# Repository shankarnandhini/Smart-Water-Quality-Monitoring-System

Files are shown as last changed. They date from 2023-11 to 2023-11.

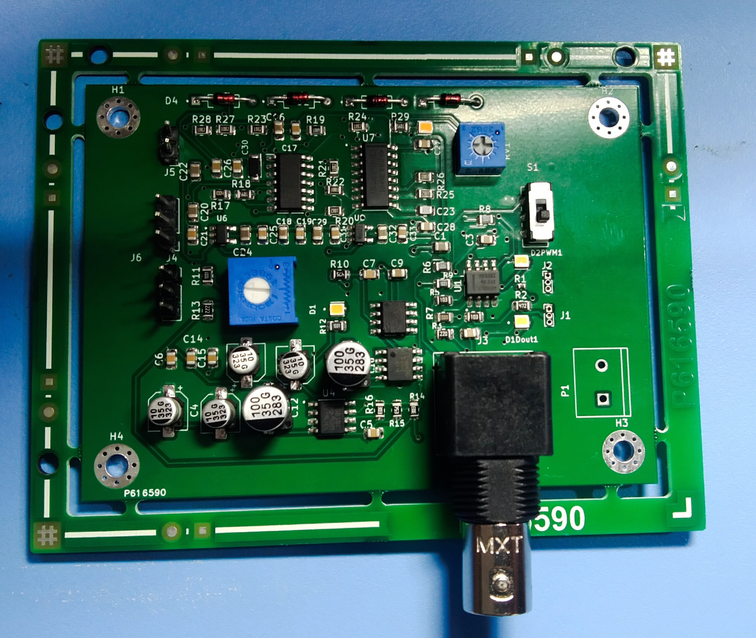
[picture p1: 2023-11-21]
Product image/IMG_20231109_144141.jpg

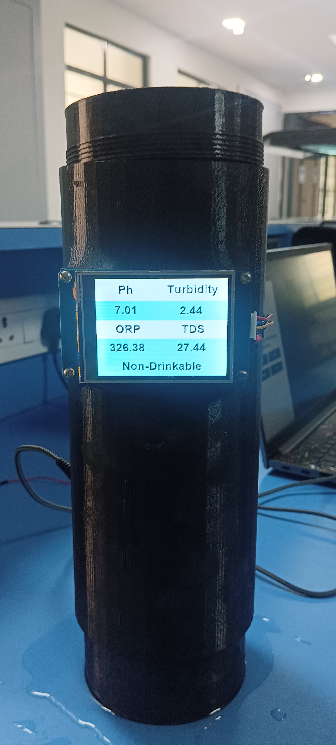
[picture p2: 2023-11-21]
Product image/IMG-20231110-WA0006.jpg

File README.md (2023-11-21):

# Smart-Water-Quality-Monitoring-System
# 🌐 Smart Water Quality Monitoring System Repository

Welcome to the repository for our Smart Water Quality Monitoring System! 🚰

## Project Overview

This repository hosts the code and documentation for an innovative smart water quality monitoring system. Our goal is to provide real-time insights into the quality of drinking water through a seamlessly integrated system.

## Key Components

- **Double-layer PCB Design:** Schematics and layouts meticulously crafted for enhanced performance.
  
- **3D-Printed Sensor Housings:** Custom-designed sensor housings using advanced 3D printing techniques.
  
- **Industrial Sensors:** Integration of industrial-grade pH, ORP, TDS, and turbidity sensors for accurate readings.

- **Raspberry Pi 4:** The core of our system, handling data processing and communication tasks efficiently.

- **Nextion HMI Touch Display:** An interactive touch display for real-time data visualization.

- **Mobile Application:** Developed using React Native, Node.js Express, and a robust database for accessible monitoring.

## Contributions

- **PCB Design:** Developed intricate double-layer PCB schematics and layouts.
  
- **3D Design and Printing:** Created and printed custom sensor housings for optimal functionality.
  
- **Hardware Integration:** Seamlessly integrated various hardware components and peripherals.
  
- **Raspberry Pi Programming:** Wrote the necessary code for Raspberry Pi, ensuring smooth data processing and communication.
  
- **Mobile Application Development:** Utilized React Native, Node.js Express, and database technologies for a user-friendly mobile application.

## Skills and Technologies Showcased

- **PCB Design:** Proficiency in crafting intricate PCB schematics and layouts.
  
- **3D Design and Printing:** Skillful creation and printing of custom 3D sensor housings.
  
- **Hardware Integration:** Expertise in integrating diverse hardware components seamlessly.
  
- **Raspberry Pi Programming:** Coding proficiency for efficient data processing on Raspberry Pi.
  
- **React Native:** Development of a mobile application for versatile accessibility.
  
- **Node.js Express:** Utilized for the backend of the mobile application.
  
- **Database Technologies:** Implemented a robust database for storing and managing data.

## License

This project is licensed under the MIT License
## Collaboration

This project is open to all collaborators! Feel free to contribute by forking the repository and creating pull requests.

## Documentation

Check the folders for comprehensive documentation related to the Smart Water Quality Monitoring System.

Feel free to explore the codebase and documentation to understand the inner workings of our Smart Water Quality Monitoring System! 💻🚀

#WaterQuality #SmartMonitoring #OpenSource #TechInnovation

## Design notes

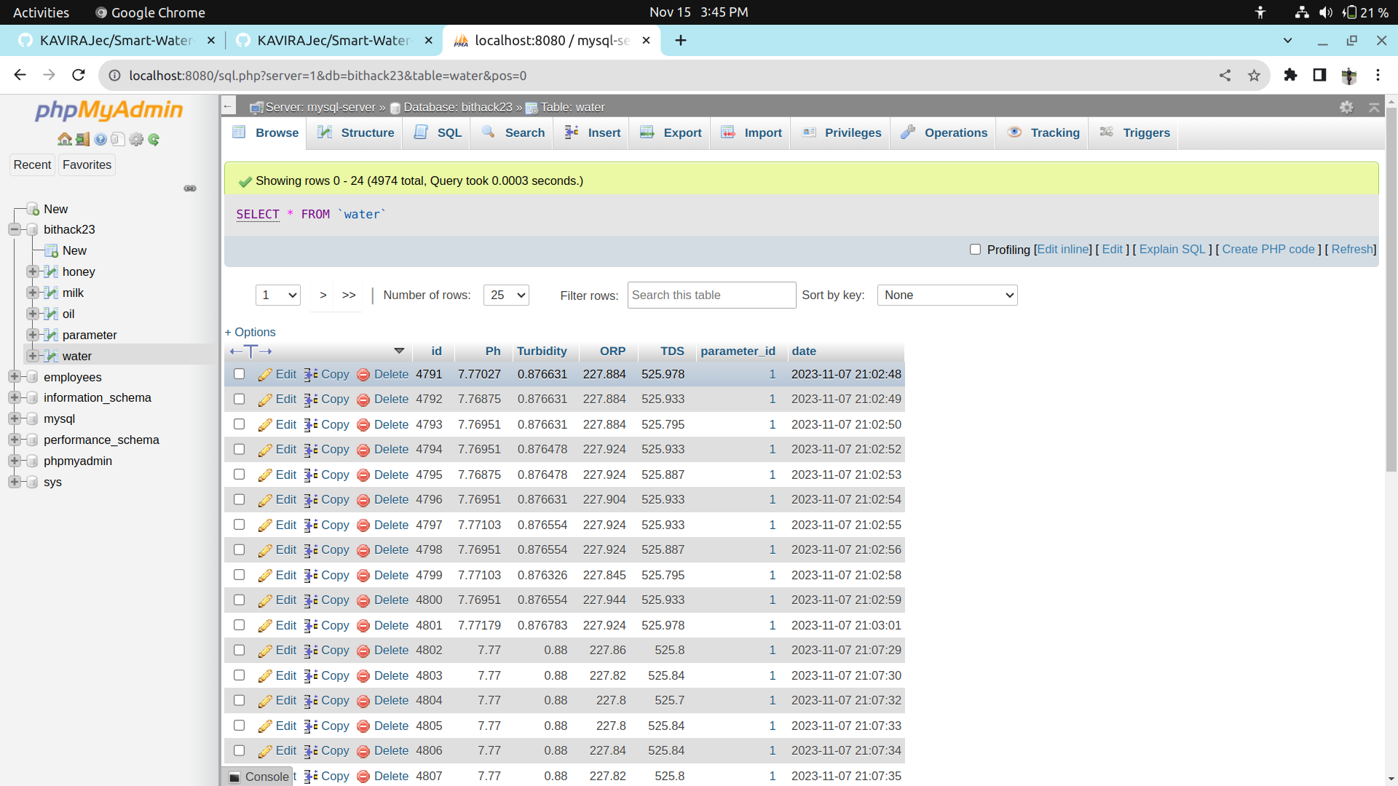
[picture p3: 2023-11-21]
Mobile Application/Screenshot from 2023-11-15 15-45-17.png

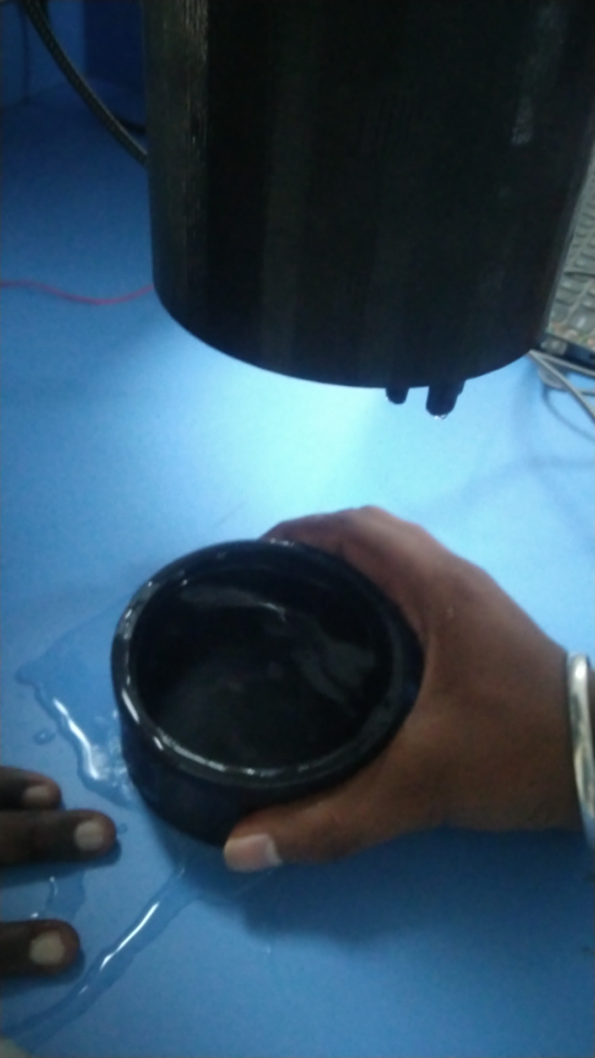
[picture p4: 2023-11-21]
Product image/Screenshot_20231115_143211.png

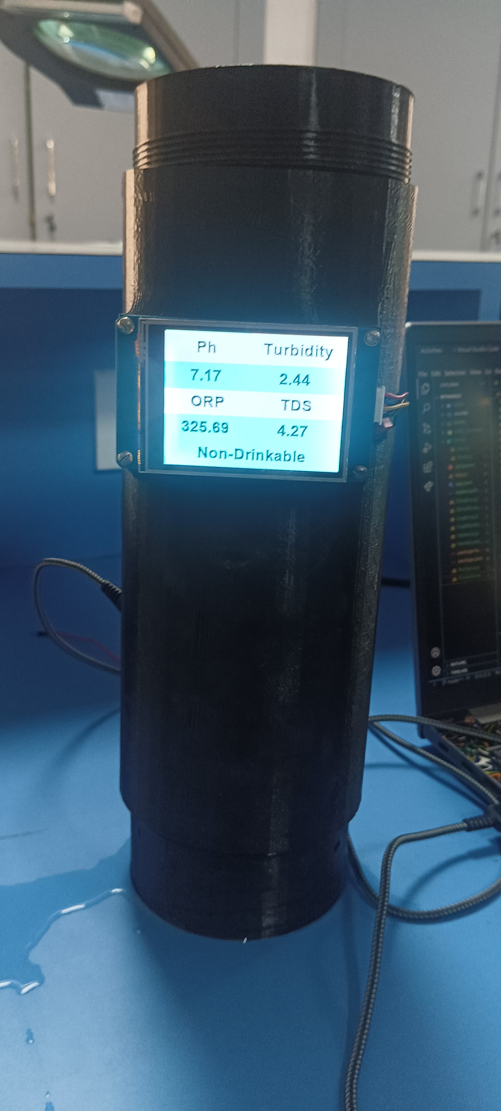
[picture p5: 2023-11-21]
Product image/IMG-20231110-WA0005.jpg

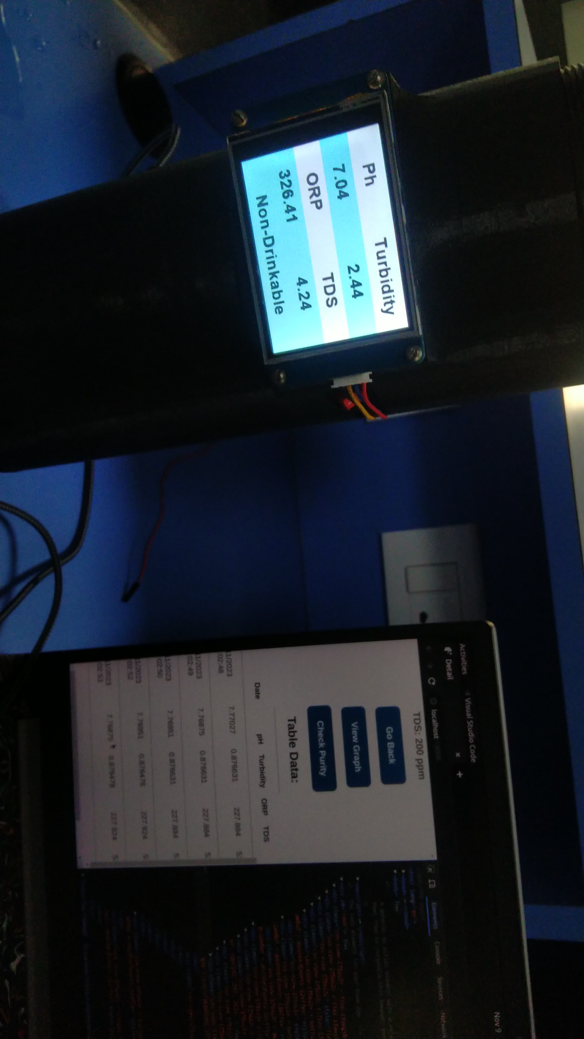
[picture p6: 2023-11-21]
Product image/Screenshot_20231115_143034.png

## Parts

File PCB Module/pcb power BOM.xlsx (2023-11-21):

BILL OF MATERIAL
Item | Quantity | Reference | Value | PART TYPE | PCB Footprint | Manufacturer Part Number | Manfacturer Name | Description
1 | 1 | C1 | 10uF | CAP | C_0805_2012Metric | CL21A106KOCLRNC | Samsung Electro-Mechanics | 10 µF ±10% 16V Ceramic Capacitor X5R 0805 (2012 Metric)(3.4mm*1.96mm)
2 | 1 | C4 | 10uF | Polarized CAP | CP_Elec_5x3 | EDK106M035A9BAA | KEMET | 10 µF 35 V Aluminum Electrolytic Capacitors Radial, Can - SMD 2000 Hrs @ 85°C(7.9mm*5.8mm)
3 | 1 | C8 | 10uF | Polarized CAP | CP_Elec_5x3 | EDK106M035A9BAA | KEMET | 10 µF 35 V Aluminum Electrolytic Capacitors Radial, Can - SMD 2000 Hrs @ 85°C(7.9mm*5.8mm)
4 | 1 | C9 | 1uF | CAP | C_0805_2012Metric | CL21B105KAFNNNE | Samsung Electro-Mechanics | 1 µF ±10% 25V Ceramic Capacitor X7R 0805 (2012 Metric)(3.6mm*1.96mm)
5 | 1 | C10 | 100uF | Polaroid CAP | CP_Elec_5x3 | EDK107M035A9HAA | KEMET | 100 µF 35 V Aluminum Electrolytic Capacitors Radial, Can - SMD 2000 Hrs @ 85°C(7.9mm*5.8mm)
6 | 1 | C11 | 10uF | Polarized CAP | CP_Elec_5x3 | EDK106M035A9BAA | KEMET | 10 µF 35 V Aluminum Electrolytic Capacitors Radial, Can - SMD 2000 Hrs @ 85°C(7.9mm*5.8mm)
7 | 1 | C12 | 100uF | Polarized CAP | CP_Elec_5x3 | EDK107M035A9HAA | KEMET | 100 µF 35 V Aluminum Electrolytic Capacitors Radial, Can - SMD 2000 Hrs @ 85°C(7.9mm*5.8mm)
8 | 1 | C13 | 10uF | Polarized CAP | CP_Elec_5x3 | EDK106M035A9BAA | KEMET | 10 µF 35 V Aluminum Electrolytic Capacitors Radial, Can - SMD 2000 Hrs @ 85°C(7.9mm*5.8mm)
9 | 1 | C16 | 4.7uF | CAP | C_0805_2012Metric | CL21A475KAQNNNE | Samsung Electro-Mechanics | 4.7 µF ±10% 25V Ceramic Capacitor X5R 0805 (2012 Metric)(3.4mm*1.96mm)
10 | 1 | C18 | 4.7uF | CAP | C_0805_2012Metric | CL21A475KAQNNNE | Samsung Electro-Mechanics | 4.7 µF ±10% 25V Ceramic Capacitor X5R 0805 (2012 Metric)(3.4mm*1.96mm)
11 | 1 | C20 | 10uF | CAP | C_0805_2012Metric | CL21A106KOCLRNC | Samsung Electro-Mechanics | 10 µF ±10% 16V Ceramic Capacitor X5R 0805 (2012 Metric)(3.4mm*1.96mm)
12 | 1 | C22 | 10uF | CAP | C_0805_2012Metric | CL21A106KOCLRNC | Samsung Electro-Mechanics | 10 µF ±10% 16V Ceramic Capacitor X5R 0805 (2012 Metric)(3.4mm*1.96mm)
13 | 1 | C24 | 10uF | CAP | C_0805_2012Metric | CL21A106KOCLRNC | Samsung Electro-Mechanics | 10 µF ±10% 16V Ceramic Capacitor X5R 0805 (2012 Metric)(3.4mm*1.96mm)
14 | 1 | C26 | 1uF | CAP | C_0805_2012Metric | CL21B105KAFNNNE | Samsung Electro-Mechanics | 1 µF ±10% 25V Ceramic Capacitor X7R 0805 (2012 Metric)(3.4mm*1.96mm)
15 | 1 | C29 | 10uF | CAP | C_0805_2012Metric | CL21A106KOCLRNC | Samsung Electro-Mechanics | 10 µF ±10% 16V Ceramic Capacitor X5R 0805 (2012 Metric)(3.4mm*1.96mm)
16 | 1 | C30 | 1uF | CAP | C_0805_2012Metric | CL21B105KAFNNNE | Samsung Electro-Mechanics | 1 µF ±10% 25V Ceramic Capacitor X7R 0805 (2012 Metric)(3.4mm*1.96mm)
17 | 1 | C32 | 10uF | CAP | C_0805_2012Metric | CL21A106KOCLRNC | Samsung Electro-Mechanics | 10 µF ±10% 16V Ceramic Capacitor X5R 0805 (2012 Metric)(3.4mm*1.96mm)
18 | 1 | R1 | 500R | RES | Resistor_SMD:R_0402_2012Metric | PNM0402E5000BST1 | Vishay Dale Thin Film | 500 Ohms ±0.1% 0.05W, 1/20W Chip Resistor 0402 (1005 Metric) Anti-Sulfur, Moisture Resistant, Non-Inductive, Non-Magnetic Thin Film(3.36mm*1.9mm)
19 | 1 | R2 | 4.7K | RES | Resistor_SMD:R_0805_2012Metric | RC0805JR-074K7L | YAGEO | 4.7 kOhms ±5% 0.125W, 1/8W Chip Resistor 0805 (2012 Metric) Moisture Resistant Thick Film
20 | 1 | R3 | 22 ohm | RES | Resistor_SMD:R_0805_2012Metric | RC0805JR-0722RL | YAGEO | 22 Ohms ±5% 0.125W, 1/8W Chip Resistor 0805 (2012 Metric) Moisture Resistant Thick Film(3.36mm*1.9mm)
21 | 1 | R4 | 10K | RES | Resistor_SMD:R_0805_2012Metric | RC0805JR-0710KL | YAGEO | 10 kOhms ±5% 0.125W, 1/8W Chip Resistor 0805 (2012 Metric) Moisture Resistant Thick Film(3.36mm*1.9mm)
22 | 1 | R5 | 10K | RES | Resistor_SMD:R_0805_2012Metric | RC0805JR-0710KL | YAGEO | 10 kOhms ±5% 0.125W, 1/8W Chip Resistor 0805 (2012 Metric) Moisture Resistant Thick Film(3.36mm*1.9mm)
23 | 1 | R6 | 1K | RES | Resistor_SMD:R_0805_2012Metric | RNCP0805FTD1K00 | Stackpole Electronics Inc | 1 kOhms ±1% 0.25W, 1/4W Chip Resistor 0805 (2012 Metric) Anti-Sulfur Thin Film(3.36mm*1.9mm)
24 | 1 | R7 | 100R | RES | Resistor_SMD:R_0805_2012Metric | RN73C2A100RBTDF | TE Connectivity Passive Product | 100 Ohms ±0.1% 0.1W, 1/10W Chip Resistor 0805 (2012 Metric) Thin Film(3.36mm*1.9mm)
25 | 1 | R8 | 1K | RES | Resistor_SMD:R_0805_2012Metric | RNCP0805FTD1K00 | Stackpole Electronics Inc | 1 kOhms ±1% 0.25W, 1/4W Chip Resistor 0805 (2012 Metric) Anti-Sulfur Thin Film(3.36mm*1.9mm)
26 | 1 | R9 | 1K | RES | Resistor_SMD:R_0805_2012Metric | RNCP0805FTD1K00 | Stackpole Electronics Inc | 1 kOhms ±1% 0.25W, 1/4W Chip Resistor 0805 (2012 Metric) Anti-Sulfur Thin Film(3.36mm*1.9mm)
27 | 1 | R10 | 4.7M | RES | Resistor_SMD:R_0805_2012Metric | RC0805JR-074M7L | YAGEO | 4.7 MOhms ±5% 0.125W, 1/8W Chip Resistor 0805 (2012 Metric) Moisture Resistant Thick Film(3.36mm*1.9mm)
28 | 1 | R11 | 1K | RES | Resistor_SMD:R_0805_2012Metric | RNCP0805FTD1K00 | Stackpole Electronics Inc | 1 kOhms ±1% 0.25W, 1/4W Chip Resistor 0805 (2012 Metric) Anti-Sulfur Thin Film(3.36mm*1.9mm)
29 | 1 | R12 | 1K | RES | Resistor_SMD:R_0805_2012Metric | RNCP0805FTD1K00 | Stackpole Electronics Inc | 1 kOhms ±1% 0.25W, 1/4W Chip Resistor 0805 (2012 Metric) Anti-Sulfur Thin Film(3.36mm*1.9mm)
30 | 1 | R13 | 2.2K | RES | Resistor_SMD:R_0805_2012Metric | RC0805JR-072K2L | YAGEO | 2.2 kOhms ±5% 0.125W, 1/8W Chip Resistor 0805 (2012 Metric) Moisture Resistant Thick Film(3.36mm*1.9mm)
31 | 1 | R14 | 30K | RES | Resistor_SMD:R_0805_2012Metric | RC0805JR-0730KL | YAGEO | 30 kOhms ±5% 0.125W, 1/8W Chip Resistor 0805 (2012 Metric) Moisture Resistant Thick Film(3.36mm*1.9mm)
32 | 1 | R15 | 75K | RES | Resistor_SMD:R_0805_2012Metric | RC0805JR-0775KL | YAGEO | 75 kOhms ±5% 0.125W, 1/8W Chip Resistor 0805 (2012 Metric) Moisture Resistant Thick Film(3.36mm*1.9mm)
33 | 1 | R16 | 30K | RES | Resistor_SMD:R_0805_2012Metric | RC0805JR-0730KL | YAGEO | 30 kOhms ±5% 0.125W, 1/8W Chip Resistor 0805 (2012 Metric) Moisture Resistant Thick Film(3.36mm*1.9mm)
34 | 1 | R17 | 1M-1% | RES-1%Tolerence | Resistor_SMD:R_0805_2012Metric | CRG0805F1M0 | TE Connectivity Passive Product | 1 MOhms ±1% 0.125W, 1/8W Chip Resistor 0805 (2012 Metric) Thick Film(3.36mm*1.9mm)
35 | 1 | R18 | 5.6K-1% | RES-1%Tolerence | Resistor_SMD:R_0805_2012Metric | RMCF0805FT5K60 | Stackpole Electronics Inc | 5.6 kOhms ±1% 0.125W, 1/8W Chip Resistor 0805 (2012 Metric) Automotive AEC-Q200 Thick Film(3.36mm*1.9mm)
36 | 1 | R19 | 6.8K-1% | RES-1%Tolerence | Resistor_SMD:R_0805_2012Metric | RMCF0805FT6K80 | Stackpole Electronics Inc | 6.8 kOhms ±1% 0.125W, 1/8W Chip Resistor 0805 (2012 Metric) Automotive AEC-Q200 Thick Film
37 | 1 | R20 | 10K-1% | RES-1%Tolerence | Resistor_SMD:R_0805_2012Metric | RMCF0805FT10K0 | Stackpole Electronics Inc | 10 kOhms ±1% 0.125W, 1/8W Chip Resistor 0805 (2012 Metric) Automotive AEC-Q200 Thick Film
38 | 1 | R21 | 10K-1% | RES-1%Tolerence | Resistor_SMD:R_0805_2012Metric | RMCF0805FT10K0 | Stackpole Electronics Inc | 10 kOhms ±1% 0.125W, 1/8W Chip Resistor 0805 (2012 Metric) Automotive AEC-Q200 Thick Film
39 | 1 | R22 | 100K-1% | RES-1%Tolerence | Resistor_SMD:R_0805_2012Metric | RMCF0805FT100K | Stackpole Electronics Inc | 100 kOhms ±1% 0.125W, 1/8W Chip Resistor 0805 (2012 Metric) Automotive AEC-Q200 Thick Film
40 | 1 | R23 | 10K-1% | RES-1%Tolerence | Resistor_SMD:R_0805_2012Metric | RMCF0805FT10K0 | Stackpole Electronics Inc | 10 kOhms ±1% 0.125W, 1/8W Chip Resistor 0805 (2012 Metric) Automotive AEC-Q200 Thick Film
41 | 1 | R24 | 10K-1% | RES-1%Tolerence | Resistor_SMD:R_0805_2012Metric | RMCF0805FT10K0 | Stackpole Electronics Inc | 10 kOhms ±1% 0.125W, 1/8W Chip Resistor 0805 (2012 Metric) Automotive AEC-Q200 Thick Film
42 | 1 | R25 | 10K-1% | RES-1%Tolerence | Resistor_SMD:R_0805_2012Metric | RMCF0805FT10K0 | Stackpole Electronics Inc | 10 kOhms ±1% 0.125W, 1/8W Chip Resistor 0805 (2012 Metric) Automotive AEC-Q200 Thick Film
43 | 1 | R26 | 100K-1% | RES-1%Tolerence | Resistor_SMD:R_0805_2012Metric | RMCF0805FT100K | Stackpole Electronics Inc | 100 kOhms ±1% 0.125W, 1/8W Chip Resistor 0805 (2012 Metric) Automotive AEC-Q200 Thick Film
44 | 1 | R27 | 10K-1% | RES-1%Tolerence | Resistor_SMD:R_0805_2012Metric | RMCF0805FT10K0 | Stackpole Electronics Inc | 10 kOhms ±1% 0.125W, 1/8W Chip Resistor 0805 (2012 Metric) Automotive AEC-Q200 Thick Film
45 | 1 | R28 | 10K-1% | RES-1%Tolerence | Resistor_SMD:R_0805_2012Metric | RMCF0805FT10K0 | Stackpole Electronics Inc | 10 kOhms ±1% 0.125W, 1/8W Chip Resistor 0805 (2012 Metric) Automotive AEC-Q200 Thick Film
46 | 1 | R29 | 5.6K-1% | RES-1%Tolerence | Resistor_SMD:R_0805_2012Metric | RMCF0805FT5K60 | Stackpole Electronics Inc | 5.6 kOhms ±1% 0.125W, 1/8W Chip Resistor 0805 (2012 Metric) Automotive AEC-Q200 Thick Film
47 | 1 | RV1 | 10K | Terminal | Potentiometer_ACP_CA9-V10_Vertical | 3362P-1-103LF | Bourns Inc. | 10 kOhms 0.5W, 1/2W PC Pins Through Hole Trimmer Potentiometer Cermet 1.0 Turn Top Adjustment(12.9mm*10.35mm)
48 | 1 | RV2 | 5K | Terminal | Potentiometer_ACP_CA9-V10_Vertical | 3386P-1-502LF | Bourns Inc. | 5 kOhms 0.5W, 1/2W PC Pins Through Hole Trimmer Potentiometer Cermet 1.0 Turn Top Adjustment(12.9mm*10.35mm)
49 | 1 | D1 | LED | White led SMD | LED_SMD:LED_0805_2012Metric | MP-2016-1100-27-90 | Luminus Devices Inc. | LED Lighting MP-2016 White, Warm 2700K 3V 60mA 110° 0806 (2016 Metric)(2.965mm*1.46mm)
50 | 1 | D1Dout1 | LED | White led SMD | LED_SMD:LED_0805_2012Metric | MP-2016-1100-27-90 | Luminus Devices Inc. | LED Lighting MP-2016 White, Warm 2700K 3V 60mA 110° 0806 (2016 Metric)(2.965mm*1.46mm)
51 | 1 | D2PWM1 | LED | White led SMD | LED_SMD:LED_0805_2012Metric | MP-2016-1100-27-90 | Luminus Devices Inc. | LED Lighting MP-2016 White, Warm 2700K 3V 60mA 110° 0806 (2016 Metric)
52 | 1 | D6 | 1N5819W | Diode | KiCad1N5819W:SODFL3618X110N | 1N5819W | SMC Diode Solutions | DIODE SCHOTTKY 40V 1A SOD123FL
53 | 1 | D7 | LED | White led SMD | LED_SMD:LED_0805_2012Metric | MP-2016-1100-27-90 | Luminus Devices Inc. | LED Lighting MP-2016 White, Warm 2700K 3V 60mA 110° 0806 (2016 Metric)
54 | 1 | J1 | Conn_01x03_pin | Male Berg Strip | Connector_PinHeader_1.00mm:PinHeader_1x03_P1.00mm_Vertical | Male Berg Strip | Male Berg Strip | Male Berg Strip
55 | 1 | J2 | Conn_01x03_pin | Male Berg Strip | Connector_PinHeader_1.00mm:PinHeader_1x03_P1.00mm_Vertical | Male Berg Strip | Male Berg Strip | Male Berg Strip
56 | 1 | J3 | Conn_Coaxial | Ph connector | Connector_Coaxial:BNC_Amphenol_B6252HB-NPP3G-50_Horizontal | 731375003 | Molex | BNC Connector Jack, Female Socket 50 Ohms Panel Mount, Through Hole, Right Angle Solder
57 | 1 | J4 | Conn_01x03_pin | Female Berg Strip | Connector_PinSocket_2.54mm:PinSocket_1x03_P2.54mm_Vertical | Female Berg Strip | Female Berg Strip | Female Berg Strip
58 | 1 | J5 | Conn_01x02_pin | Male Berg Strip | Connector_PinHeader_2.54mm:PinHeader_1x02_P2.54mm_Vertical | Male Berg Strip | Male Berg Strip | Male Berg Strip
59 | 1 | J6 | Conn_01x03_pin | Male Berg Strip | Connector_PinHeader_2.54mm:PinHeader_1x02_P2.54mm_Vertical | Male Berg Strip | Male Berg Strip | Male Berg Strip
60 | 1 | U1 | LMV358IDR | IC 8 PIN | Package_CSP:LFCSP-8_2x2mm_P0.5mm | LMV358IDR | Texas Instruments (https://www.digikey.in/en/supplier-centers/texas-instruments) | IC OPAMP GP 2 CIRCUIT 8SOIC, General Purpose Amplifier 2 Circuit Rail-to-Rail 8-SOIC
61 | 1 | U2 | CA3140AMZ | IC 8 PIN | CA3140AMZ:SOIC127P600X175-8N | CA3140AMZ | Renesas Electronics America Inc | (CA3140AMZ)General Purpose Amplifier 1 Circuit 8-SOIC
62 | 1 | U3 | ADM8660AMZ | IC 8 PIN | ADM8660ARZ:SOIC127P600X175-8N | ADM8660ARZ | Analog Devices Inc. (https://www.digikey.in/en/supplier-centers/analog-devices) | Charge Pump Switching Regulator IC Negative Fixed -Vin 1 Output 100mA 8-SOIC (0.154", 3.90mm Width)
63 | 1 | U4 | TL081BCDG4 | IC 8 PIN | TL081BCDG4:SOIC127P599X175-8N | TL081BCD | Texas Instruments | (TL081BCDG4)J-FET Amplifier 1 Circuit 8-SOIC
64 | 1 | U5 | LMV324 | IC 14 PIN | Package_SO:SOIC-14_3.9x8.7mm_P1.27mm | LMV324IDT | STMicroelectronics | IC OPAMP GP 4 CIRCUIT 14SO
65 | 1 | U6 | TPS60400DBVR | IC 5 PIN | TPS60400DBVR:SOT95P280X145-5N | TLV73330PDBVR | Texas Instruments (https://www.digikey.in/en/supplier-centers/texas-instruments) | Linear Voltage Regulator IC Positive Fixed 1 Output 300mA SOT-23-5
66 | 1 | U7 | CD4060BM | IC 16 PIN | CD4060BM:SOIC127P600X175-16N | CD4060BM | Texas Instruments | IC BINARY COUNTER 14-BIT 16SOIC
67 | 1 | U8 | TLV73330PDBVR | IC 5PIN | TLV73330PDBVR:SOT95P280X145-5N | TLV73330PDBVR | Texas Instruments | Linear Voltage Regulator IC Positive Fixed 1 Output 300mA SOT-23-5
68 | 1 | S1 | SW_DPDT_x2 | 8 PIN SWITCH | Button_Switch_SMD:SW_DPDT_CK_JS202011JCQN | JS202011CQN | C&K | Slide Switch DPDT Through Hole
69 | 1 | P1 | 282837-2 | GREEN CONN THT | 282837-2:TE_282837-2 | GREEN CONN THT | GREEN CONN THT | GREEN CONN THT
70 | 1 | C3 | 100nF | CAP | C_0805_2012Metric | MT05B104M500BD | Aillen | 0.1 µF ±20% 50V Ceramic Capacitor X7R 0805 (2012 Metric)
71 | 1 | C2 | 100nF | CAP | C_0805_2012Metric | MT05B104M500BD | Aillen | 0.1 µF ±20% 50V Ceramic Capacitor X7R 0805 (2012 Metric)
72 | 1 | C5 | 100nF | CAP | C_0805_2012Metric | MT05B104M500BD | Aillen | 0.1 µF ±20% 50V Ceramic Capacitor X7R 0805 (2012 Metric)
73 | 1 | C6 | 100nF | CAP | C_0805_2012Metric | MT05B104M500BD | Aillen | 0.1 µF ±20% 50V Ceramic Capacitor X7R 0805 (2012 Metric)
74 | 1 | C14 | 100nF | CAP | C_0805_2012Metric | MT05B104M500BD | Aillen | 0.1 µF ±20% 50V Ceramic Capacitor X7R 0805 (2012 Metric)
75 | 1 | C15 | 100nF | CAP | C_0805_2012Metric | MT05B104M500BD | Aillen | 0.1 µF ±20% 50V Ceramic Capacitor X7R 0805 (2012 Metric)
76 | 1 | C17 | 100nF | CAP | C_0805_2012Metric | MT05B104M500BD | Aillen | 0.1 µF ±20% 50V Ceramic Capacitor X7R 0805 (2012 Metric)
77 | 1 | C25 | 100nF | CAP | C_0805_2012Metric | MT05B104M500BD | Aillen | 0.1 µF ±20% 50V Ceramic Capacitor X7R 0805 (2012 Metric)
78 | 1 | C19 | 100nF | CAP | C_0805_2012Metric | MT05B104M500BD | Aillen | 0.1 µF ±20% 50V Ceramic Capacitor X7R 0805 (2012 Metric)
79 | 1 | C21 | 100nF | CAP | C_0805_2012Metric | MT05B104M500BD | Aillen | 0.1 µF ±20% 50V Ceramic Capacitor X7R 0805 (2012 Metric)
80 | 1 | C27 | 100nF | CAP | C_0805_2012Metric | MT05B104M500BD | Aillen | 0.1 µF ±20% 50V Ceramic Capacitor X7R 0805 (2012 Metric)
81 | 1 | C28 | 100nF | CAP | C_0805_2012Metric | MT05B104M500BD | Aillen | 0.1 µF ±20% 50V Ceramic Capacitor X7R 0805 (2012 Metric)
82 | 1 | C31 | 100nF | CAP | C_0805_2012Metric | MT05B104M500BD | Aillen | 0.1 µF ±20% 50V Ceramic Capacitor X7R 0805 (2012 Metric)
83 | 1 | C33 | 100nF | CAP | C_0805_2012Metric | MT05B104M500BD | Aillen | 0.1 µF ±20% 50V Ceramic Capacitor X7R 0805 (2012 Metric)
84 | 1 | C23 | 1nF | CAP | C_0805_2012Metric | C0805C102KDRACAUTO | KEMET | 1000 pF ±10% 1000V (1kV) Ceramic Capacitor X7R 0805 (2012 Metric)
85 | 1 | C7 | 2.2nF | CAP | C_0805_2012Metric | C0805C222K3GEC7800 | KEMET | 2200 pF ±10% 25V Ceramic Capacitor C0G, NP0 0805 (2012 Metric)
86 | 1 | D3 | 1N4148 | Diode | 1N4148:DIOAD829W49L456D191 | 1N4148 | onsemi | Diode 100 V 200mA Through Hole DO-35
87 | 1 | D4 | 1N4149 | Diode | 1N4148:DIOAD829W49L456D192 | 1N4149 | onsemi | Diode 100 V 200mA Through Hole DO-35
88 | 1 | D5 | 1N4150 | Diode | 1N4148:DIOAD829W49L456D193 | 1N4150 | onsemi | Diode 100 V 200mA Through Hole DO-35
89 | 1 | D2 | 1N4151 | Diode | 1N4148:DIOAD829W49L456D194 | 1N4151 | onsemi | Diode 100 V 200mA Through Hole DO-35

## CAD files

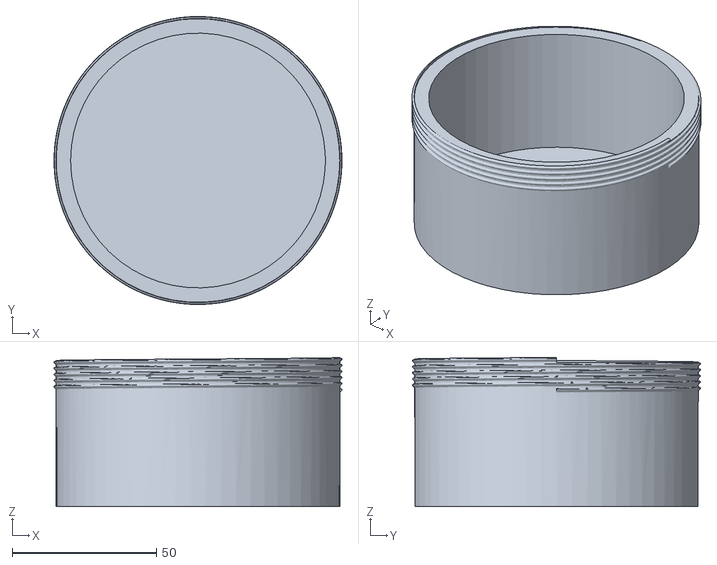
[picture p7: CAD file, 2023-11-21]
3D Designing/bottom cup.STL
99.9 x 99.9 x 51.7

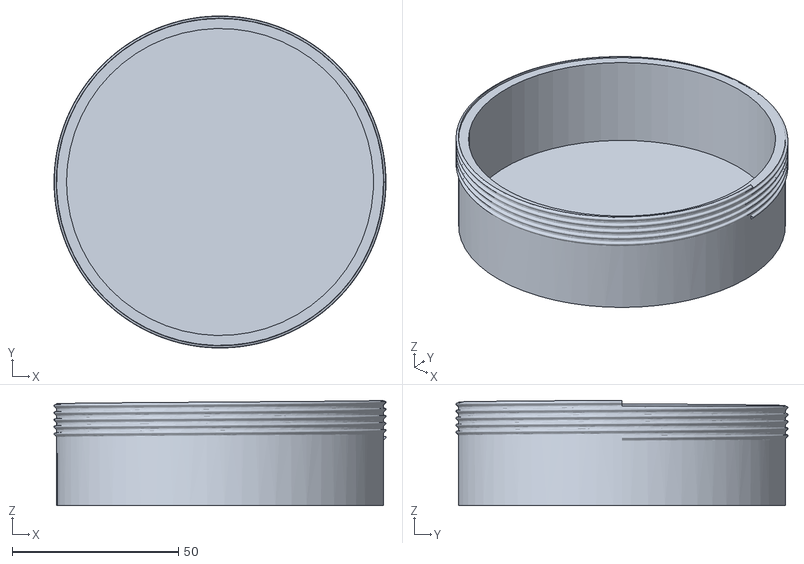
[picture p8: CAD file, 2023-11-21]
3D Designing/top cap.STL
99.9 x 99.9 x 31.7

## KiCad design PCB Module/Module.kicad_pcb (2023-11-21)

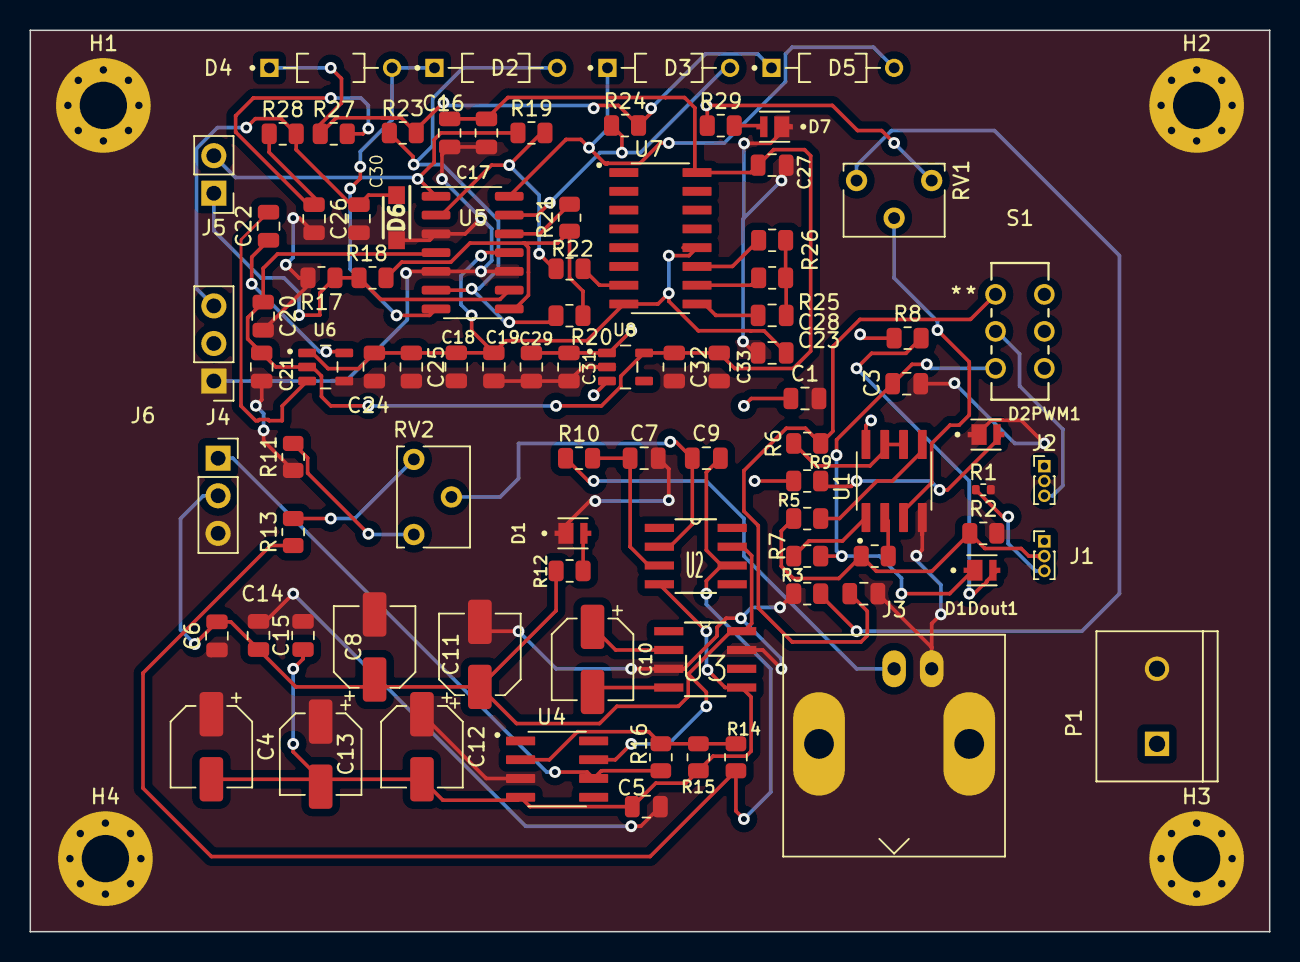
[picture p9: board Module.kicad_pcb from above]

Board: 2 copper layers, 83.8 x 61.0 mm, 93 parts (0 on the bottom side), 50 nets.

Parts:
C1, C20, C22, C24, C29, C32: 10uF; C_0805_2012Metric
C2, C3, C5, C6, C14, C15, C17, C19, C21, C25, C27, C28, C31, C33: 100nF; C_0805_2012Metric
C4, C8, C11, C13: 10uF; CP_Elec_5x3
C7: 2.2nF; C_0805_2012Metric
C9, C26, C30: 1uF; C_0805_2012Metric
C10, C12: 100uF; CP_Elec_5x3
C16, C18: 4.7uF; C_0805_2012Metric
C23: 1nF; C_0805_2012Metric
D1, D1Dout1, D2PWM1, D7: MP-2016-1100-27-90; LED_MP-2016-1100-27-90
D2, D3, D4, D5: 1N4148; DIOAD829W49L456D191
D6: 1N5819W; SODFL3618X110N
H1, H2, H3, H4: MountingHole_Pad; MountingHole_3.2mm_M3_Pad_Via
J1, J2: Conn_01x03_Pin; PinHeader_1x03_P1.00mm_Vertical
J3: Conn_Coaxial; BNC_Amphenol_B6252HB-NPP3G-50_Horizontal
J4: Conn_01x03_Pin; PinSocket_1x03_P2.54mm_Vertical
J5: Conn_01x02_Pin; PinHeader_1x02_P2.54mm_Vertical
J6: Conn_01x03_Pin; PinHeader_1x03_P2.54mm_Vertical
P1: 282837-2; TE_282837-2
R1: 500R; R_0402_1005Metric
R2: 4.7K; R_0805_2012Metric
R3: 22R; R_0805_2012Metric
R4, R5: 10K; R_0805_2012Metric
R6, R8, R9, R12: 1K; R_0805_2012Metric
R7: 100R; R_0805_2012Metric
R10: 4.7M; R_0805_2012Metric
R11: 1k; R_0805_2012Metric
R13: 2.2K; R_0805_2012Metric
R14, R16: 30K; R_0805_2012Metric
R15: 75K; R_0805_2012Metric
R17: 1M-1%; R_0805_2012Metric
R18, R29: 5.6K-1%; R_0805_2012Metric
R19: 6.8K-1%; R_0805_2012Metric
R20, R21, R23, R24, R25, R27, R28: 10K-1%; R_0805_2012Metric
R22, R26: 100K-1%; R_0805_2012Metric
RV1: 10K; Potentiometer_Vishay_T73XX_Horizontal
RV2: 5K; Potentiometer_Vishay_T73XX_Horizontal
S1: JS202011CQN; SWITCH_011CQN
U1: LMV358IDR; SOIC127P599X175-8N
U2: CA3140AMZ; SOIC127P600X175-8N
U3: ADM8660ARZ; SOIC127P600X175-8N
U4: TL081BCDG4; SOIC127P599X175-8N
U5: LMV324; SOIC-14_3.9x8.7mm_P1.27mm
U6: TPS60400DBVR; SOT95P280X145-5N
U7: CD4060BM; SOIC127P600X175-16N
U8: TLV73330PDBVR; SOT95P280X145-5N

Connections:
+3.0V: C16.1, C17.1, C20.1, C21.1, C27.1, C32.1, C33.1, U5.4 (V+), U6.2 (IN), U7.16 (VCC), U8.5 (OUT)
+5V: C6.2, C8.1, C11.1, C14.1, J4.2, R12.1, U2.7 (V+), U3.8 (V+), U4.7 (VCC+)
-3.0V: C18.1, C19.1, C24.1, C25.1, C28.2, U5.11 (V-), U6.1 (OUT), U7.8 (GND), U7.12 (RESET)
-5V: C4.2, C5.1, C12.2, C13.2, C15.1, R15.2, U2.4 (V-), U3.5 (OUT), U4.4 (VCC-)
/Dout: C3.1, D1Dout1.C, R7.2, S1.3
/sensor_out: J2.3, S1.2
GND: C1.2, C2.2, C3.2, C4.1, C5.2, C6.1, C7.2, C8.2, C11.2, C12.1, C13.1, C14.2, C15.2, C16.2, C17.2, C18.2, C19.2, C20.2, C21.2, C24.2, C25.2, C26.2, C27.2, C28.1, C29.2, C30.2, C31.2, C32.2, C33.2, D1.C, D2PWM1.C, D6.2 (A), D7.C, H1.1, H2.1, H3.1, H4.1, J2.2, J3.2 (Ext), J4.3, J6.1, P1.2, R1.2, R2.2, R3.1, R11.1, R17.2, U1.4 (V-), U3.3 (GND), U3.7 (SD), U4.3 (IN+), U5.3 (+), U5.5 (+), U5.10 (+), U6.4 (GND), U8.2 (GND)
unnamed: C2.1, R6.2, S1.1
unnamed: C23.1, R25.1, R26.1
unnamed: C26.1, R27.2, R28.1
unnamed: D1.A, R12.2
unnamed: D1Dout1.A, R8.2
unnamed: D2.C, D4.A, U5.7
unnamed: D2PWM1.A, R9.2
unnamed: D3.C, D5.A, U5.14
unnamed: D4.C, D5.C, R23.2, R24.2, R27.1
unnamed: C30.1, D6.1 (K), J6.3, R28.2
unnamed: D7.A, R29.2
unnamed: J1.2, R2.1, R4.1, R5.1
unnamed: J1.3, R1.1
unnamed: J3.1 (In), R10.1
unnamed: J4.1, R16.2, U4.6 (OUT)
unnamed: J5.1, R17.1, R18.1, U5.9 (-)
unnamed: J5.2, R19.1, U5.1
unnamed: R3.2, RV1.3
unnamed: R11.2, RV2.3
unnamed: R13.2, RV2.1
unnamed: R18.2, R20.1, R21.1, U5.8
unnamed: RV1.2, U1.3 (INA+)
unnamed: R4.2, U1.2 (INA-)
unnamed: R5.2, U1.5 (INB+)
unnamed: R6.1, U1.6 (INB-), U1.7 (OUT_B)
unnamed: R7.1, U1.1 (OUT_A)
unnamed: C9.1, RV2.2, U2.2 (INV._INPUT)
unnamed: C7.1, R10.2, U2.3 (NON-INV._INPUT)
unnamed: C9.2, R13.1, R14.1, U2.6 (OUTPUT)
unnamed: C10.1, U3.2 (CAP+)
unnamed: C10.2, U3.4 (CAP-)
unnamed: R14.2, R15.1, R16.1, U4.2 (IN-)
unnamed: R19.2, R22.1, U5.2 (-)
unnamed: D2.A, R20.2, R23.1, U5.6 (-)
unnamed: R21.2, U5.12 (+)
unnamed: D3.A, R24.1, U5.13 (-)
unnamed: C22.1, U6.5 (CFLY+)
unnamed: C22.2, U6.3 (CFLY-)
unnamed: C23.2, U7.9 (EN1)
unnamed: R25.2, U7.10 (EN2)
unnamed: R26.2, U7.11 (EN3)
unnamed: R22.2, U7.7 (Q4)
VCC: C1.1, C29.1, C31.1, J1.1, J2.1, J6.2, P1.1, R8.1, R9.1, R29.1, RV1.1, U1.8 (V+), U8.1 (IN), U8.3 (EN)

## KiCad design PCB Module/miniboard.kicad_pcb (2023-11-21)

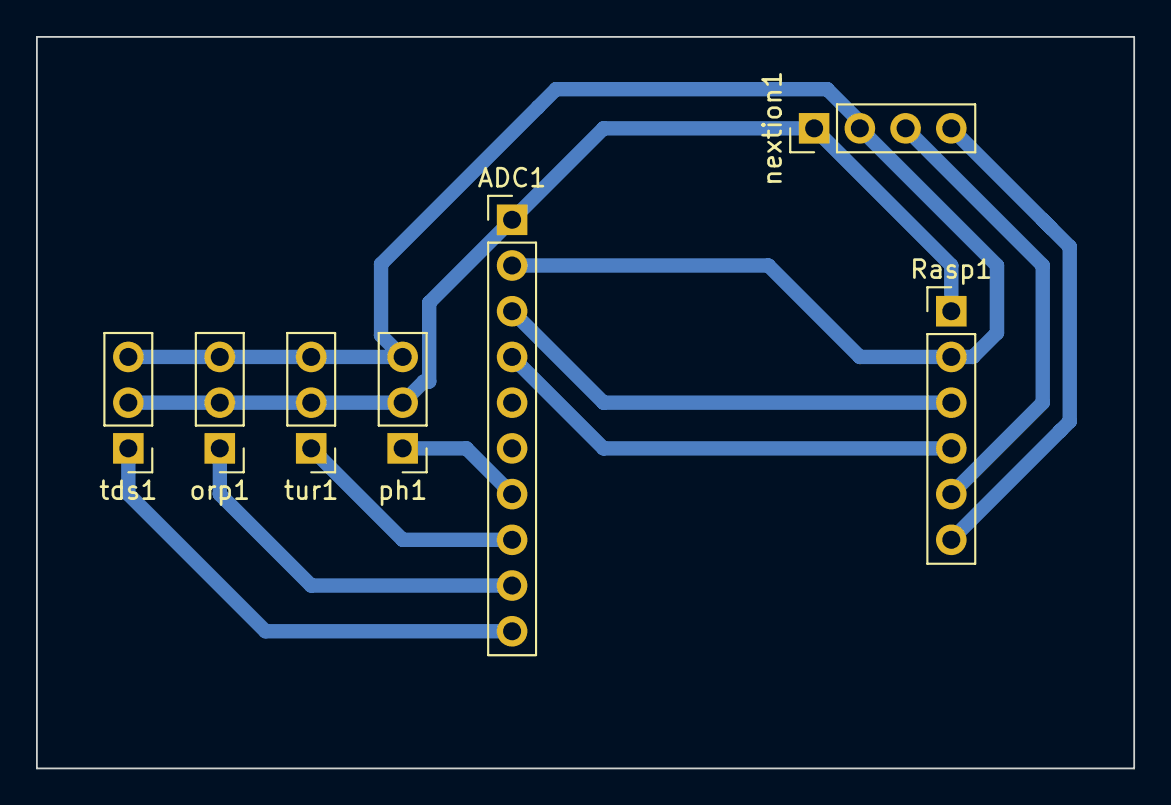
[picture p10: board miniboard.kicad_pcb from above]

Board: 2 copper layers, 61.0 x 40.6 mm, 7 parts (0 on the bottom side), 10 nets.

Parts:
ADC1: Conn_01x10_Pin; PinHeader_1x10_P2.54mm_Vertical
Rasp1: Conn_01x06_Pin; PinHeader_1x06_P2.54mm_Vertical
nextion1: Conn_01x04_Pin; PinHeader_1x04_P2.54mm_Vertical
orp1: Conn_01x03_Pin; PinHeader_1x03_P2.54mm_Vertical
ph1: Conn_01x03_Pin; PinHeader_1x03_P2.54mm_Vertical
tds1: Conn_01x03_Pin; PinHeader_1x03_P2.54mm_Vertical
tur1: Conn_01x03_Pin; PinHeader_1x03_P2.54mm_Vertical

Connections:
+5V: ADC1.1, Rasp1.1, nextion1.1, orp1.2, ph1.2, tds1.2, tur1.2
GND: ADC1.2, Rasp1.2, nextion1.2, orp1.3, ph1.3, tds1.3, tur1.3
unnamed: ADC1.3, Rasp1.3
unnamed: ADC1.4, Rasp1.4
unnamed: ADC1.7, ph1.1
unnamed: ADC1.8, tur1.1
unnamed: ADC1.9, orp1.1
unnamed: ADC1.10, tds1.1
unnamed: Rasp1.5, nextion1.3
unnamed: Rasp1.6, nextion1.4

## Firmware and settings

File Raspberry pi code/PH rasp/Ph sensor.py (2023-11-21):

import board
import busio
import adafruit_ads1x15.ads1115 as ADS
from adafruit_ads1x15.analog_in import AnalogIn
import time

# Create an I2C object
i2c = busio.I2C(board.SCL, board.SDA)

# Create an ADS1115 object
ads = ADS.ADS1115(i2c)

pH_sensor = AnalogIn(ads, ADS.P0)
# Configure the ADS1115 for single-ended input
ads.gain = 1

# Set the slope and intercept values
ads.slope = -0.0007380073800738007
ads.intercept = 12475.00516605166

# Start a loop to read the pH sensor
while True:

    # Read the voltage from the pH sensor
    voltage = pH_sensor.value

    # Calculate the pH
    pH = voltage * ads.slope + ads.intercept

    # Print the pH to the console
    print(pH)

    # Wait for 1 second
    time.sleep(1)

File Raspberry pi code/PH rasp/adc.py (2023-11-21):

import Adafruit_ADS1x15
import time

# Create an ADS1115 ADC instance
adc = Adafruit_ADS1x15.ADS1115()

# Constants for calibration (values need to be adjusted based on your sensor and calibration)
ph_4_voltage = 2.056  # Voltage output of the sensor in pH 4 solution
ph_7_voltage = 1.563  # Voltage output of the sensor in pH 7 solution

# Loop indefinitely
while True:
    # Read the raw ADC value from the sensor
    raw_value = adc.read_adc(0, gain=1)  # Assuming the sensor is connected to channel 0

    # Convert raw ADC value to voltage
    voltage = (raw_value * 4.096) / 32767.0  # 4.096V is the full-scale range of the ADC

    # Calculate the slope and offset
    slope = (ph_7_voltage - ph_4_voltage) / (7 - 4)  # (V7 - V4) / (pH7 - pH4)
    offset = ph_4_voltage - (slope * 4)  # V4 - (slope * pH4)

    # Convert voltage to pH using the calibration parameters
    ph_value = (voltage - offset) / slope

    # Print the pH value
    print("pH Value: {:.2f}".format(ph_value))

    # Wait for a moment before taking the next measurement (adjust the delay as needed)
    time.sleep(1)
